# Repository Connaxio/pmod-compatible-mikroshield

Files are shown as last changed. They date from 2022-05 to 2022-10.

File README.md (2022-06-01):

# Pmod<sup>TM</sup> Compatible mikroShield
The Pmod<sup>TM</sup> Compatible mikroShield is a mikroBUS<sup>TM</sup> to Digilent Pmod<sup>TM</sup> Compatible add-on board. It further increases the compatibility of mikroBUS<sup>TM</sup> mainboards by adding compatibility with any board that complies with the Digilent Pmod<sup>TM</sup> Interface Specification.

The Digilent Pmod<sup>TM</sup> Compatible connector provides 8 signal pins and 4 power pins that can also be used with breadboard jumper cables to connect many breakout boards, such as the ones distributed by Adafruit and SparkFun.

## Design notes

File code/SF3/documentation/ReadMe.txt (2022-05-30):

reference materials can be found at the Digilent resource center

https://reference.digilentinc.com/reference/pmod/pmodsf3/start

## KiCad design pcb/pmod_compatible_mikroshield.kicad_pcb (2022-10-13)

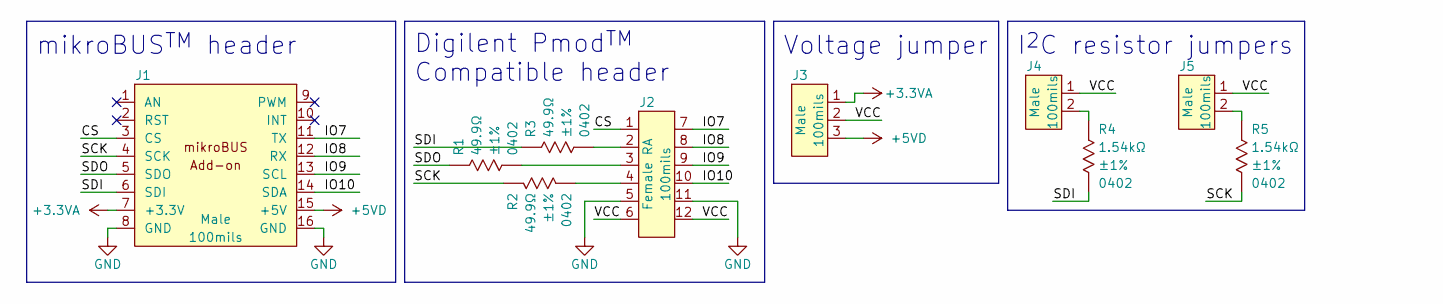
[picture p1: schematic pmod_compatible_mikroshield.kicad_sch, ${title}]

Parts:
J1: CON_HDR_MIKROBUS_ADDON_TH; Voltage 350V
J2: CON_HDR_100MILS_F_TH_RA_2X6; Voltage 350V
J3: CON_HDR_100MILS_M_TH_1X3; Voltage 350V
J4, J5: CON_HDR_100MILS_M_TH_1X2; Voltage 350V
R1, R2, R3: RES_49.9Ω_1%_0402; RES_0402_1005M; Tolerance ±1%; Voltage 50V; Manufacturer Part Number RMCF0402FT49R9
R4, R5: RES_1.54KΩ_1%_0402; RES_0402_1005M; Tolerance ±1%; Voltage 50V; Manufacturer Part Number RMCF0402FT1K54

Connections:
+3.3VA: J1.7 (+3.3V), J3.1
+5VD: J1.15 (+5V), J3.3
/CS: J1.3 (CS), J2.1
/IO7: J1.11 (TX), J2.7
/IO8: J1.12 (RX), J2.8
/IO9: J1.13 (SCL), J2.9
/IO10: J1.14 (SDA), J2.10
/SCK: J1.4 (SCK), R2.1, R5.2
/SDI: J1.6 (SDI), R3.1, R4.2
/SDO: J1.5 (SDO), R1.1
/VCC: J2.6, J2.12, J3.2, J4.1, J5.1
GND: J1.8 (GND), J1.16 (GND), J2.5, J2.11
unnamed: J2.2, R3.2
unnamed: J2.3, R1.2
unnamed: J2.4, R2.2
unnamed: J4.2, R4.1
unnamed: J5.2, R5.1

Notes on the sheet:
Voltage jumper
Digilent Pmod^{TM} Compatible header
mikroBUS^{TM} header
I^{2}C resistor jumpers

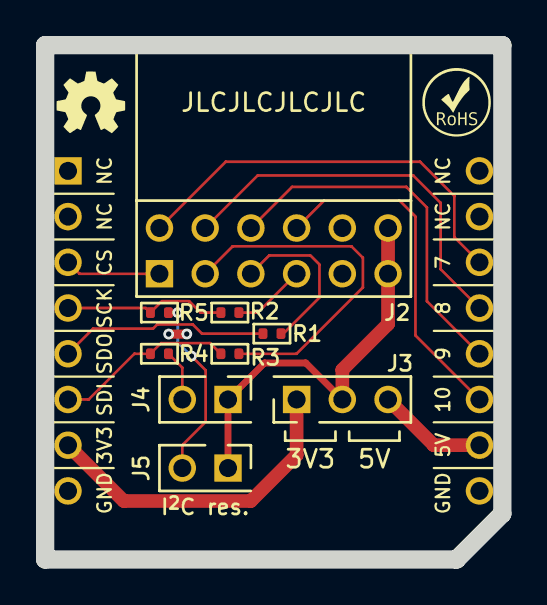
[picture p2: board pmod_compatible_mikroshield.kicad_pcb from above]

Board: 2 copper layers, 25.4 x 28.6 mm, 10 parts (0 on the bottom side), 17 nets.

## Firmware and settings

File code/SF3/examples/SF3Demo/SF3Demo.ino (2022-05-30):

#include "SF3.h"

/**************************************************/
/* PmodSF3 Demo                                   */
/**************************************************/
/*    Author: Samuel Lowe                         */
/*    Copyright 2016, Digilent Inc.               */
/*                                                */
/*   Made for use with chipKIT uC32               */
/**************************************************/
/*  Module Description:                           */
/*                                                */
/*    This module implements a demo application   */
/*    of the PmodSF3.                             */
/*                                                */
/*  Functionality:                                */
/*                                                */  
/*    This module initializes the PmodSF3         */
/*    then reads some flash memory. Then writes   */
/*    a page and reads it back                    */
/*                                                */
/**************************************************/
/*  Revision History:                             */
/*                                                */
/*      10/7/2016(SamL): Created                  */
/*                                                */
/**************************************************/

SF3 mySF3;

#define BASE_ADDRESS 0x004000

void printData (unsigned int address);

int id, address, data, i = 0;
int wp_pin = 18;
int hld_pin = 23;
int rst_pin = 10;

void setup() {
  // put your setup code here, to run once:
  uint8_t page[256];

  // Initialise secondary pins
  //pinMode(wp_pin, OUTPUT);
  //pinMode(hld_pin, OUTPUT);
  pinMode(SS, OUTPUT);
  pinMode(rst_pin, OUTPUT);

  //digitalWrite(wp_pin, LOW);
  //digitalWrite(hld_pin, HIGH);
  // Reset flash chip
  digitalWrite(rst_pin, LOW);
  delay(100);
  digitalWrite(rst_pin, HIGH);
  delay(100);
  
  mySF3.begin();
  Serial.begin(115200);
  

  //print off device ID
  id = mySF3.getDeviceID();
  Serial.print("id: ");
  Serial.println(id, HEX);

  //mySF3.writeSR(0x02);
  //Serial.print("SR test: ");
  //Serial.println(mySF3.readSR());

  
  //print first couple members of the base address
  printData(BASE_ADDRESS);
  printData(BASE_ADDRESS+1);
  printData(BASE_ADDRESS+2);
  printData(BASE_ADDRESS+3);
  printData(BASE_ADDRESS+4);
  


  mySF3.writeEnable();
  
  mySF3.subSectorErase(BASE_ADDRESS);
  delay(10);

  Serial.print("sr check: " );
  Serial.println(mySF3.readSR());
  Serial.println("after the subsector is erased");
  printData(BASE_ADDRESS);
  printData(BASE_ADDRESS+1);
  printData(BASE_ADDRESS+2);
  printData(BASE_ADDRESS+3);
  printData(BASE_ADDRESS+4);

  //populate array
  for(int i = 0; i < 256; i++){
    page[i] = i;
  }

  mySF3.writeEnable();
  mySF3.writePage(page, BASE_ADDRESS);
  
  Serial.print("sr check after write: " );
  Serial.println(mySF3.readSR());

  for(i = 0; i < 16; i++){
    printData(BASE_ADDRESS + i);
  }
  
}

void loop() {
  // put your main code here, to run repeatedly:

}

//prints data at a given address
void printData (unsigned int address)
{
    data = mySF3.normalRead(address);
    Serial.print("Address 0x");
    Serial.print(address, HEX);
    Serial.print(": 0x");
    Serial.println(data, HEX);
}

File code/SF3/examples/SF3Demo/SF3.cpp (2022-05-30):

/************************************************************************/
/*                                                      */
/*  SF3.cpp  --  Function Declarations for SF3               */
/*                                                      */
/************************************************************************/
/*  Author:   Samuel Lowe                               */
/*  Copyright (c) 2016, Digilent Inc. All rights reserved.          */

/*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
  You should have received a copy of the GNU Lesser General Public
  License along with this library; if not, write to the Free Software
  Foundation, Inc., 51 Franklin St, Fifth Floor, Boston, MA  02110-1301  USA
*/
/************************************************************************/
/*  Module Description:                         */
/*                                            */
/*  This is the function cpp file for the SF3 library         */
/*                                            */
/************************************************************************/
/*  Revision History:                           */
/*                                            */
/*  10/5/2016 (AndrewH) : started                         */
/*  10/7/2016(SamL): created                   */
/*                                            */
/************************************************************************/

#include "SF3.h"


/* ------------------------------------------------------------ */
/*  SF3
**
**  Parameters:
**    none
**
**  Return Value:
**    none
**
**  Errors:
**    none
**
**  Description:
**    starts the spi controller the sf3 uses
*/
void SF3::begin() {
  SPI.begin();

  SPI.beginTransaction(SPISettings(500000, SPI_MSBFIRST, SPI_MODE0));
}

/* ------------------------------------------------------------ */
/*  getDeviceID
**
**  Parameters:
**    none
**
**  Return Value:
**    
**
**  Errors:
**    none
**
**  Description:
**    queries and recieves the DeviceID of the SF3 (0x19)
*/
int SF3::getDeviceID() {
  uint8_t rcvByte[3];

  
  waitForWrite();
  writeEnable();

  digitalWrite(SS, 0);
  SPI.transfer(COMMAND_READ_ID);
  rcvByte[0] = SPI.transfer(0x00);
  rcvByte[1] = SPI.transfer(0x00);
  rcvByte[2] = SPI.transfer(0x00);
  digitalWrite(SS, 1);

  return rcvByte[2];
}

/* ------------------------------------------------------------ */
/*  normalRead
**
**  Parameters:
**    address: address to read
**
**  Return Value:
**    value: byte at selected address
**
**  Errors:
**    none
**
**  Description:
**    reads a byte value from flash memory
*/
uint8_t SF3::normalRead(int address) {
  uint8_t sndByte[4]= { 0 };
  uint8_t rcvByte;

  sndByte[0] = COMMAND_RANDOM_READ;

  sndByte[1] = (address >> 16);
  sndByte[2] = (address >> 8);
  sndByte[3] = address;

  
  waitForWrite();
  writeEnable();

  digitalWrite(SS, 0);
  SPI.transfer(sndByte[0]);
  SPI.transfer(sndByte[1]);
  SPI.transfer(sndByte[2]);
  SPI.transfer(sndByte[3]);
  
  rcvByte = SPI.transfer(0x00);
  digitalWrite(SS, 1);
  
  return rcvByte;
}


/* ------------------------------------------------------------ */
/*  writePage
**
**  Parameters:
**    uint8_t page: page data to write to the sf3
**    address: address to read
**
**  Return Value:
**    value: byte at selected address
**
**  Errors:
**    none
**
**  Description:
**    writes a page to memory. see data sheet for consequences 
**    of different start addreesses
*/
void SF3::writePage(uint8_t* writeData, int address) {
  uint8_t sndBytes[4] = { 0 };

  sndBytes[0] = COMMAND_PAGE_PROGRAM;
  sndBytes[1] = (uint16_t)(address >> 16);
  sndBytes[2] = (uint16_t)(address >> 8);
  sndBytes[3] = (uint16_t)address;

  
  
  waitForWrite();
  writeEnable();

  digitalWrite(SS, 0);
  SPI.transfer(sndBytes[0]);
  SPI.transfer(sndBytes[1]);
  SPI.transfer(sndBytes[2]);
  SPI.transfer(sndBytes[3]);
  

  for(int i = 0; i < 256; i++){
    SPI.transfer(writeData[i]);
  }
  digitalWrite(SS, 1);
}

/* ------------------------------------------------------------ */
/*  subSectorErase
**
**  Parameters:
**    address: address of sector to erase (any address in sector is valid)
**
**  Return Value:
**    none
**
**  Errors:
**    none
**
**  Description:
**    erases a subsector of memory
*/
void SF3::subSectorErase(int address) {
  uint8_t sndBytes[4] = { 0 };

  sndBytes[0] = COMMAND_SUB_SECTOR_ERASE;
  sndBytes[1] = (address >> 16);
  sndBytes[2] = (address >> 8);
  sndBytes[3] = address;
  
  waitForWrite();
  writeEnable();

  digitalWrite(SS, 0);
  SPI.transfer(sndBytes[0]);
  SPI.transfer(sndBytes[1]);
  SPI.transfer(sndBytes[2]);
  SPI.transfer(sndBytes[3]);
  digitalWrite(SS, 1);
}


/* ------------------------------------------------------------ */
/*  bulkErase
**
**  Parameters:
**    none
**
**  Return Value:
**    none
**
**  Errors:
**    none
**
**  Description:
**    erases all of the memory
*/
void SF3::bulkErase() {
  
  
  writeSR(0x00);
  
  waitForWrite();
  writeEnable();

  digitalWrite(SS, 0);
  SPI.transfer(COMMAND_BULK_ERASE);
  digitalWrite(SS, 1);
}

/* ------------------------------------------------------------ */
/*  writeSR
**
**  Parameters:
**    setReg: the byte to write to the status reg
**
**  Return Value:
**    none
**
**  Errors:
**    none
**
**  Description:
**    sets the status register
*/
void SF3::writeSR(uint8_t setReg) {
  waitForWrite();

  writeEnable();

  digitalWrite(SS, 0);
  SPI.transfer(COMMAND_WRITE_STATUSREG);
  SPI.transfer(setReg);
  digitalWrite(SS, 1);

}

/* ------------------------------------------------------------ */
/*  writeEnable
**
**  Parameters:
**    none
**
**  Return Value:
**    none
**
**  Errors:
**    none
**
**  Description:
**    prepares the device to write
*/
void SF3::writeEnable() {
  digitalWrite(SS, 0);
  SPI.transfer(COMMAND_WRITE_ENABLE);
  digitalWrite(SS, 1);

}

/* ------------------------------------------------------------ */
/*  readSR
**
**  Parameters:
**    none
**
**  Return Value:
**    none
**
**  Errors:
**    none
**
**  Description:
**    prepares the device to write
*/
uint8_t SF3::readSR(void) {
  uint8_t SR;

  digitalWrite(SS, 0);
  SPI.transfer(COMMAND_READ_STATUSREG); // command read status register
  
  SR = SPI.transfer(0x00);
  digitalWrite(SS, 1);

  return SR;
}

/* ------------------------------------------------------------ */
/*  waitForWrite
**
**  Parameters:
**    none
**
**  Return Value:
**    none
**
**  Errors:
**    none
**
**  Description:
**    waits for the status to read that the device can be writtin
*/
void SF3::waitForWrite() {
  uint8_t SR;

  SR = readSR();

  while(SR & 0x1)
    SR = readSR();
}

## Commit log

2022-05-09 Add oshw logo.
    [pmod_d_mikroshield.kicad_pcb]
2022-05-12 Silkscreen fixes
    [pmod_d_mikroshield.kicad_pcb, pmod_d_mikroshield.kicad_sch]
2022-05-29 Fix name compliance with Pmod license Add RoHS logo Fix pin names
    [pmod_compatible_mikroshield.kicad_pcb, pmod_compatible_mikroshield.kicad_sch]
2022-05-30 Fix inverted SDO/SDI Add source resistors to signal lines
    [pmod_compatible_mikroshield.kicad_pcb, pmod_compatible_mikroshield.kicad_sch]
2022-05-30 Add Digilent SF3 SPI flash working example
2022-10-13 Fix paste mask and license
    [pmod_compatible_mikroshield.kicad_pcb]

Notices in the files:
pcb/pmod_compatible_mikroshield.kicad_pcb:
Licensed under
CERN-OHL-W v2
